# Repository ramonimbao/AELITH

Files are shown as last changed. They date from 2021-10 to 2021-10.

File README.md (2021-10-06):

# ÆLITH (or AELITH)

[][cc-by-nc-sa]

### Through-hole Alice-layout Keyboard



*Thanks to dumbothedog for the photo.*

### Partslist
 |Count|Part|
 |-|-|
 |1|ATmega32A 40 pin DIP|
 |1|40 pin DIP socket|
 |1|HRO-TYPE-C-M-12|
 |1|500 mA polyfuse|
 |2|6mm momentary push buttons|
 |1|16 MHz quarz crystal|
 |1|4.7 uF electrolytic capacitor|
 |2|100 nF ceramic disk capacitor|
 |2|22 pF ceramic disk capacitor|
 |2|68 Ω resistor|
 |2|1.5 kΩ resistor|
 |2|5.1 kΩ resistor|
 |2|3.6 V zener diode|
 |71|universal switching diode|

This work is licensed under a
[Creative Commons Attribution-NonCommercial-ShareAlike 4.0 International License][cc-by-nc-sa].

This design may be freely produced, modified, and manufactured for **PERSONAL USE ONLY** and may not be reproduced in physical form for public sale.

[][cc-by-nc-sa]

[cc-by-nc-sa]: http://creativecommons.org/licenses/by-nc-sa/4.0/
[cc-by-nc-sa-image]: https://licensebuttons.net/l/by-nc-sa/4.0/88x31.png
[cc-by-nc-sa-shield]: https://img.shields.io/badge/License-CC%20BY--NC--SA%204.0-lightgrey.svg

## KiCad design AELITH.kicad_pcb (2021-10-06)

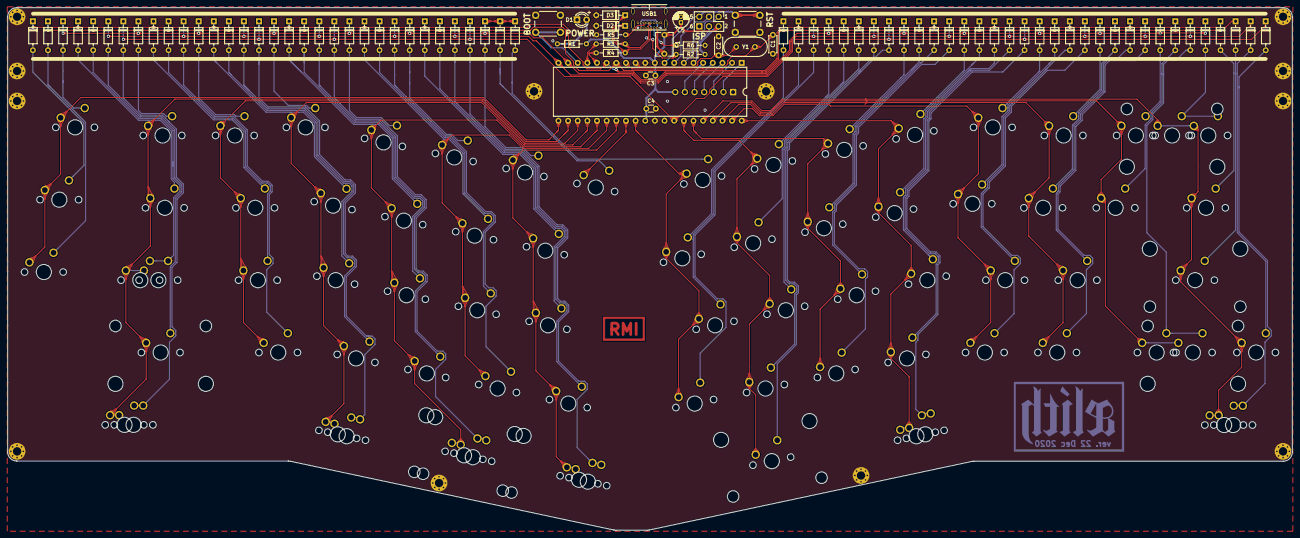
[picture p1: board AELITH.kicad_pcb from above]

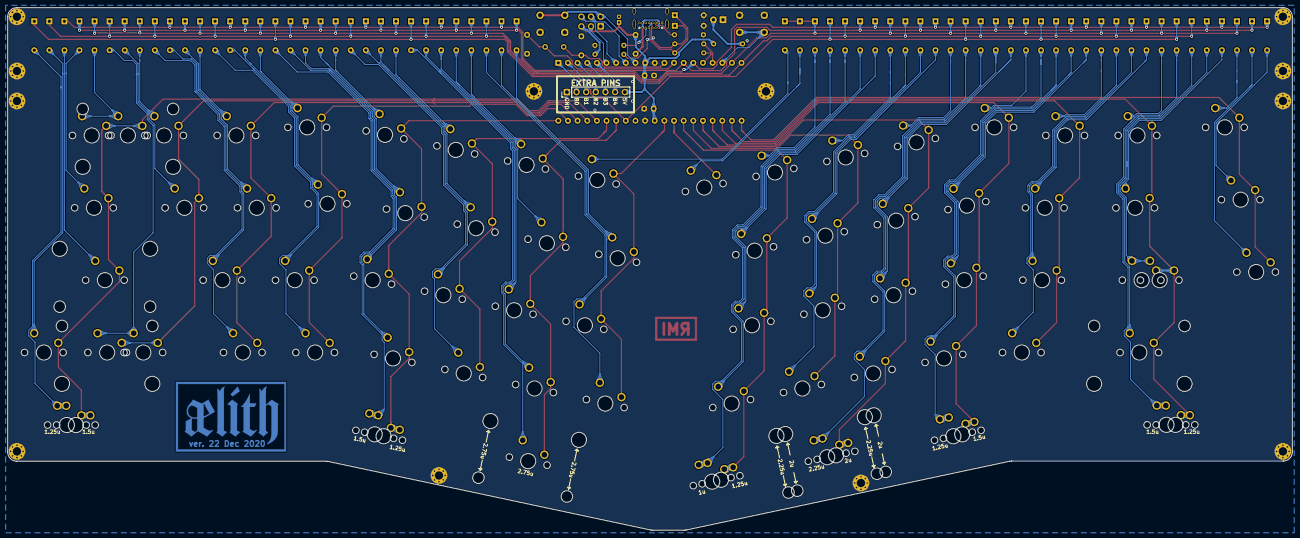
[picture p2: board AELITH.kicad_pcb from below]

Board: 2 copper layers, 338.3 x 137.6 mm, 177 parts (2 on the bottom side), 109 nets.

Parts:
C1, C2: 22pF; C_Disc_D4.3mm_W1.9mm_P5.00mm
C3, C4: 100nF; C_Disc_D3.0mm_W1.6mm_P2.50mm
C5: 10uF; CP_Radial_D4.0mm_P1.50mm
D1: LED; LED_D3.0mm
D2, D3: 3.6V; D_DO-35_SOD27_P7.62mm_Horizontal
D4, D5, D6, D7, D8, D9, D10, D11, D12, D13, D14, D15, D16, D17, D18, D19, D20, D21, D22, D23, D24, D25, D26, D28, D29, D30, D31, D32, D33, D34, D35, D36, D37, D38, D39, D40, D41, D42, D44, D45, D46, D47, D48, D49, D51, D52, D53, D54, D55, D56, D57, D59, D60, D61, D62, D63, D64, D65, D66, D67, D68, D69, D70, D71, D72, D73: 1N4148; D_DO-35_SOD27_P7.62mm_Horizontal
F1: 500mA; C_Disc_D6.0mm_W4.4mm_P5.00mm
G1: Signature
G2: Logo; AELITH_Logo
H1, H2, H3, H4, H5, H6, H7, H8, H9, H10, H11, H12: M2; MountingHole_2.2mm_M2_Pad_Via
J1: Conn_02x03_Odd_Even; PinHeader_2x03_P2.54mm_Vertical
J2: Conn_01x07; PinHeader_1x07_P2.54mm_Vertical
MX1, MX2, MX3, MX4, MX5, MX6, MX7, MX8, MX9, MX10, MX11, MX12, MX13, MX14, MX15, MX16, MX18, MX20, MX21, MX22, MX23, MX24, MX26, MX27, MX28, MX29, MX30, MX31, MX32, MX34, MX36, MX37, MX38, MX39, MX40, MX42, MX43, MX44, MX45, MX46, MX47, MX52, MX53, MX54, MX55, MX56, MX58, MX59, MX60, MX61, MX62, MX63, MX65, MX77: MX-LED; MXOnly-1U-NoLED
MX17: MX-LED; MXOnly-2U-NoLED
MX19, MX33, MX67, MX68, MX72, MX73: MX-LED; MXOnly-1.5U-NoLED
MX35, MX64: MX-LED; MXOnly-1.75U-NoLED
MX49, MX76: MX-LED; MXOnly-2.25U-ReversedStabilizers-NoLED
MX50, MX70, MX74, MX75, MX78, MX79: MX-LED; MXOnly-1.25U-NoLED
MX51: MX-LED; MXOnly-2.25U-NoLED
MX66: MX-LED; MXOnly-2.75U-NoLED
MX69: MX-LED; MXOnly-2U-ReversedStabilizers-NoLED
MX71: MX-LED; MXOnly-2.75U-ReversedStabilizers-NoLED
R1, R2: 1.5k; R_Axial_DIN0204_L3.6mm_D1.6mm_P7.62mm_Horizontal
R3, R4: 75; R_Axial_DIN0204_L3.6mm_D1.6mm_P7.62mm_Horizontal
R5, R6: 5.1k; R_Axial_DIN0204_L3.6mm_D1.6mm_P7.62mm_Horizontal
SW1, SW2: SW_Push; SW_PUSH_6mm
U1: ATmega32A-PU; DIP-40_W15.24mm
USB1: USB_C_Receptacle_USB2.0; USB_C_GCT_USB4085
Y1: 16MHz; Crystal_HC49-4H_Vertical

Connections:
+5V: C3.1, C4.1, C5.1, F1.1, J1.2, J2.7, R1.2, R2.2, U1.10, U1.30
/A0: MX12.1, MX29.1, MX45.1, MX61.1, MX72.1, MX78.1, U1.40
/A1: MX13.1, MX30.1, MX46.1, MX62.1, U1.39
/A2: MX14.1, MX31.1, MX47.1, MX63.1, U1.38
/A3: MX15.1, MX32.1, MX64.1, MX66.1, U1.37
/A4: MX16.1, MX17.1, MX33.1, MX49.1, MX65.1, MX73.1, MX79.1, U1.36
/A5: MX11.1, MX28.1, MX44.1, MX60.1, U1.35
/A6: MX10.1, MX27.1, MX43.1, MX59.1, MX71.1, U1.34
/A7: D67.1, D68.1, D69.1, D70.1, D71.1, D72.1, D73.1, U1.33
/B0: J2.2, U1.1
/B1: J2.3, U1.2
/B2: J2.4, U1.3
/B3: J2.5, U1.4
/B4: J2.6, U1.5
/BOOT: SW2.1, U1.18
/C0: MX2.1, MX19.1, MX35.1, MX50.1, MX51.1, MX67.1, MX74.1, U1.22
/C1: MX3.1, MX20.1, MX36.1, MX52.1, U1.23
/C2: MX4.1, MX21.1, MX37.1, MX53.1, MX68.1, MX75.1, U1.24
/C3: MX5.1, MX22.1, MX38.1, MX54.1, MX69.1, MX76.1, U1.25
/C4: MX6.1, MX23.1, MX39.1, MX55.1, U1.26
/C5: MX7.1, MX24.1, MX40.1, MX56.1, MX70.1, MX77.1, U1.27
/C6: MX8.1, U1.28
/C7: MX9.1, MX26.1, MX42.1, MX58.1, U1.29
/D0: D36.1, D37.1, D38.1, D39.1, D40.1, D41.1, D42.1, D44.1, D45.1, D46.1, D47.1, D48.1, D49.1, D51.1, U1.14
/D1: D20.1, D21.1, D22.1, D23.1, D24.1, D25.1, D26.1, D28.1, D29.1, D30.1, D31.1, D32.1, D33.1, D34.1, D35.1, U1.15
/D5: D4.1, D5.1, D6.1, D7.1, D8.1, D9.1, D10.1, D11.1, D12.1, D13.1, D14.1, D15.1, D16.1, D17.1, D18.1, D19.1, U1.19
/D6: D52.1, D53.1, D54.1, D55.1, D56.1, D57.1, D59.1, D60.1, D61.1, D62.1, D63.1, D64.1, D65.1, D66.1, U1.20
/D7: MX1.1, MX18.1, MX34.1, U1.21
/DBUS+: D3.1, R4.1, USB1.A6, USB1.B6
/DBUS-: D2.1, R2.1, R3.1, USB1.A7, USB1.B7
D+: R4.2, U1.16
D-: R3.2, U1.17
GND: C1.2, C2.1, C3.2, C4.2, C5.2, D1.1, D2.2, D3.2, H1.1, H2.1, H3.1, H4.1, H5.1, H6.1, H7.1, H8.1, H9.1, H10.1, H11.1, H12.1, J1.6, J2.1, R5.1, R6.2, SW1.1, SW2.2, U1.11, U1.31, USB1.B1, USB1.B12, USB1.S1
MISO: J1.1, U1.7
MOSI: J1.4, U1.6
NRST: J1.5, SW1.2, U1.9
unnamed: C1.1, U1.13, Y1.1
unnamed: C2.2, U1.12, Y1.2
unnamed: D1.2, R1.1
unnamed: D4.2, MX1.2
unnamed: D5.2, MX2.2
unnamed: D6.2, MX3.2
unnamed: D7.2, MX4.2
unnamed: D8.2, MX5.2
unnamed: D9.2, MX6.2
unnamed: D10.2, MX7.2
unnamed: D11.2, MX8.2
unnamed: D12.2, MX9.2
unnamed: D13.2, MX10.2
unnamed: D14.2, MX11.2
unnamed: D15.2, MX12.2
unnamed: D16.2, MX13.2
unnamed: D17.2, MX14.2
unnamed: D18.2, MX15.2
unnamed: D19.2, MX16.2, MX17.2
unnamed: D20.2, MX18.2
unnamed: D21.2, MX19.2
unnamed: D22.2, MX20.2
unnamed: D23.2, MX21.2
unnamed: D24.2, MX22.2
unnamed: D25.2, MX23.2
unnamed: D26.2, MX24.2
unnamed: D28.2, MX26.2
unnamed: D29.2, MX27.2
unnamed: D30.2, MX28.2
unnamed: D31.2, MX29.2
unnamed: D32.2, MX30.2
unnamed: D33.2, MX31.2
unnamed: D34.2, MX32.2
unnamed: D35.2, MX33.2
unnamed: D36.2, MX34.2
unnamed: D37.2, MX35.2, MX50.2
unnamed: D38.2, MX36.2
unnamed: D39.2, MX37.2
unnamed: D40.2, MX38.2
unnamed: D41.2, MX39.2
unnamed: D42.2, MX40.2
unnamed: D44.2, MX42.2
unnamed: D45.2, MX43.2
unnamed: D46.2, MX44.2
unnamed: D47.2, MX45.2
unnamed: D48.2, MX46.2
unnamed: D49.2, MX47.2
unnamed: D51.2, MX49.2
unnamed: D52.2, MX51.2
unnamed: D53.2, MX52.2
unnamed: D54.2, MX53.2
unnamed: D55.2, MX54.2
unnamed: D56.2, MX55.2
unnamed: D57.2, MX56.2
unnamed: D59.2, MX58.2
unnamed: D60.2, MX59.2
unnamed: D61.2, MX60.2
unnamed: D62.2, MX61.2
unnamed: D63.2, MX62.2
unnamed: D64.2, MX63.2
unnamed: D65.2, MX64.2, MX66.2
unnamed: D66.2, MX65.2
unnamed: D67.2, MX67.2, MX74.2
unnamed: D68.2, MX68.2, MX75.2
unnamed: D69.2, MX69.2, MX76.2
unnamed: D70.2, MX70.2, MX77.2
unnamed: D71.2, MX71.2
unnamed: D72.2, MX72.2, MX78.2
unnamed: D73.2, MX73.2, MX79.2
unnamed: R5.2, USB1.B5
unnamed: R6.1, USB1.A5
SCLK: J1.3, U1.8
VBUS: F1.2, USB1.A4, USB1.A9, USB1.B4, USB1.B9

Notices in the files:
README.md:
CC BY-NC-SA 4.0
